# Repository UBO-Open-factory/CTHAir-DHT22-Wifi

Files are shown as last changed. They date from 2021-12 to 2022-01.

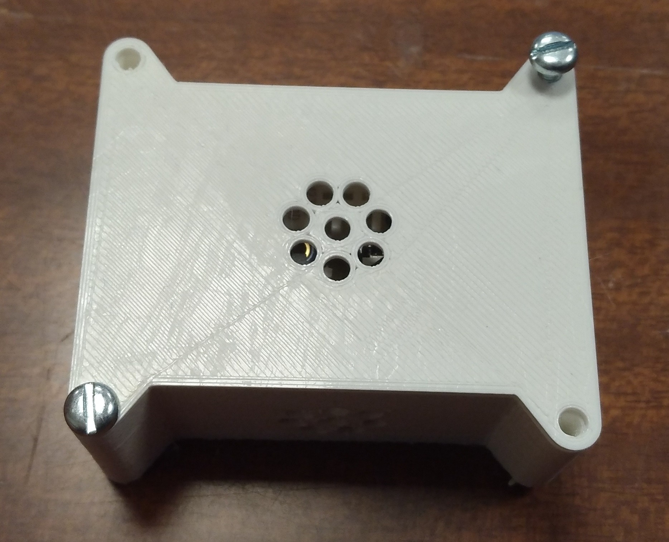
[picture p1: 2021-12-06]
Production/Photos/Boitier.jpg

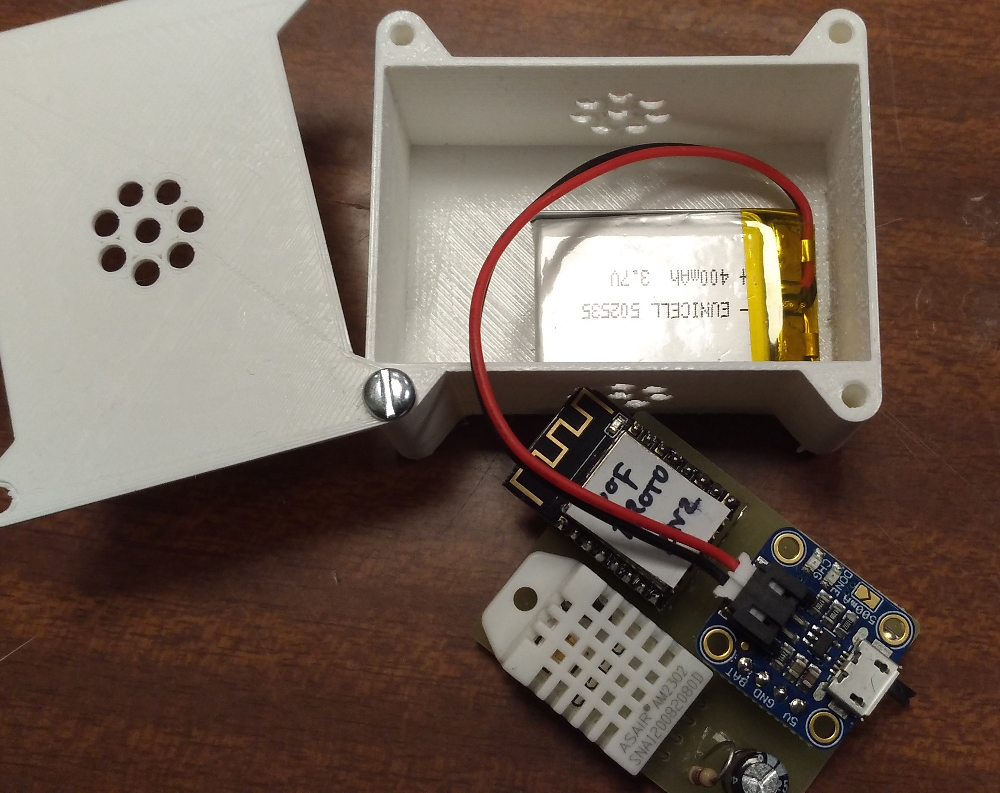
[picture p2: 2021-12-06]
Production/Photos/IMG_20211124_111949.jpg

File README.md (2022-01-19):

# CTHAir-DHT22-Wifi
Capteur de température et d'hygrométrie (DHT22) connecté à un réseau Wifi

Le capteur présenté ici permet de mesurer la température et l'hygrométrie d'un lieu puis d'envoyer ces informations par Wifi à un serveur de données.

<h1>Description</h1>
    Il intègre :
    <ul>
        <li>un capteur spécifique pouvant mesurer à la fois la température et l'hygrométrie de l'air</li>
        <li>un microcontrôleur gérant le fonctionnement de l'ensemble</li>
        <li>un chargeur de batterie  (https://www.robotshop.com/eu/fr/chargeur-batteries-lipo-micro-usb-adafruit.html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)</li>
        <li>un interrupteur On/Off</li>
        <li>Quelques composants discrets pour le fonctionnement du microcontôleur.</li>
    </ul>
    Il se présente sous la forme d'un petit boitier de 58 x 50 x 26 mm perc de quelques trous intégrant la carte électronique et une batterie.

<h1>Fonctionnement</h1>
    Le module réalise une mesure de température, une mesure d'hygrométrie et une mesure de la tension de la batterie.<br>
    Il se connecte ensuite à un réseau Wifi dont on lui a comuniqué les paramètres (SSID et mot de passe).<br>
    Puis il envoie les données sur un centre de données  dont on lui a communiqué l'adresse. Parmi les données envoyées figure un identifiant qui permettra au centre de données de savoir de quel module il reçoit des informations et donc comment les enregistrer.<br>
    Enfin il se met en veille pour une durée programmée après laquelle il recommencera un cycle de mesure/envoi/sommeil...

<h1>Electronique</h1>
    <h2>Version 2.4</h2>
    Elle est composée :
    <ul>
        <li>d'une carte électronique qui mesure 36 x 44 mm. Elle est composée d'un circuit simple face. Le schéma électrique et le schéma d'implantation sont données dans le répertoire "Electronique" au format Eagle et PDF.</li>
        <li>d'un ESP8266-12 Wifi (https://www.conrad.fr/p/joy-it-esp8266-module-uart-wifi-esp12-f-1-pcs-1707668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). Il est programmé pour réaliser toutes les fonctions du module. </li>
        <li>d'un chargeur pour batteries LiPo (https://www.adafruit.com/product/1904). Ce chrageur peut accepter toue batterie LiPo de 3.7V jusqu'à 5000 mAh. Il possède un prise batterie spécifique (JST2) ainsi qu'un prise de charge type USB mico.</li>
        <li>d'un capteur de température et hygrométrie relative (HR) DHT22 (https://www.robot-maker.com/shop/capteurs/31-dht22-31.html). Il peut mesurer des températures comprises entre 140 et +80°C avec une marge d'erreur de 0.5°C. Il peut mesurer un taux d'humidité de 0% à 100% avec une marge d'erreur de 2%.</li>
        <li>un régulateur "low drop" (placé côté pistes de la carte électronique) dont le rôle est de ramener la tension batterie à une tension de acceptable pour le fonctionnement du module (typiquement 3,3 V).</li>
        <li>Quelques composants dont les rôles sont multiples (filtrage d'alimentation, polarisation de certaines broches de l'ESP8266 pour le démarrage).</li>
    </ul>
    L'assemblage de la carte électronique est décrit dans le document "Assemblage" dans le répertoire "Documentation".
    <br>
    <h2>Version 3.1</h2>
    Elle est  composée des mêmes composants que l'électronique V2.4. La seule différence tient dans la carte électronique dont le schéma électrique est légèrement différent pour alimenter le DHT22 par un GPIO de l'ESP.
    Son montage est identique à la carte V2.4 à l'exception de l'emplacement des résistances. Les fichiers Eagle fournis donnent la nouvelle implantation.

<h1>Programme</h1>
    Le programme est décomposé en plusieurs fichiers disponibles dans le répertoire "programmation".
    L'ESP se programme (par exemple) avec l'IDE Arduino et à l'aide du programmateur décrit ci-dessous.
    <h2>Version 1.0</h2>
    Cette version utilise le protocole HTTP associé à un Fingerprint.
    <ul>
        <li>Le fichier "CTHAir_DHT22_Wifi_v1_0.ino" qui contient le programme principal.</li>
        <li>Le fichier "variables.h" qui contient les variables principales de fonctionnement du programme. Notamment l'identifiant du module qui sera transmis avec les données mesurées. Cet identifiant permettra qu centre de données de savoir quel module envoie des données.</li>
        <li>Le fichier "wifi_data.h" qui contient les paramètres de connection à un réseau Wifi. Les deux paramètres sont a adapter en fonction du réseau auquel on veut se connecter.</li>
        <li>Le fichier "server_data.h" qui contient les paramètres du serveur de données sur lequel on veut envoyer les données (hote, URL, port et fingerprint).</li>
        <li>Le fichier "type_converter.h" qui contient quelques fonctions utiles pour trnasformer des variables numériques en chaines de caractères formatées.</li>
    </ul>
    il est nécessaire de renseigner : 
        ssid et mod de passe dans le fichier "wifi_data.h"
        host, url et fingerprint dans le fichier "server_data.h"
        identifiant dans "variables.h"
    <br>
<h2>Version 1.1</h2>
    Dérivée de la version 1.0 elle n'utilise plus de fingerprint. LE reste fonctionne de la même manière.
    Il sera donc nécessaire de renseigner les mêmes données que dans la version 1.0 (sauf le fingerprint) avant de programmer l'ESP12.
    <h2>Version 2.0</h2>
    Similaire à la version 1.0 sur le plan de l'organisation. Seul la partie principale change pour s'adapter à l'alimentation du DHT22 par un GPIO.
    De ce fait il sera nécessaire de renseigner les mêmes données que dans la version 1.0 (sauf le fingerprint) avant de programmer l'ESP12.

<h1>Programmateur V1</h1>
    La programmation de l'ESP nécessite passe par une liaison UART et un convertisseur UART/USB pour communiquer avec un ordinateur de bureau. La solution adoptée a été de modifier un NodeMCU en enlevant l'ESP présent sur celui-ci et en le remplaçant par deux connecteurs. Ceci permet d'insérer des ESP à programmer.<br>
    Mise en garde : le désoudage de l'ESP et la soudure des connecteurs est un peu délicate. Une photo du programmateur est dsponible dans le répertoire "programmateur"

<h1>Batteries</h1>
    Les batteries utilisables sont de type LiPo 3.7V. Plusieurs capacités sont disponibles (250 mAh, 400 mAh, 1000 mAh et 5000 mAh).

<h1>Boitier V1</h1>
        Cette version n'accepte que les batteries jusqu'à 1000mAh inclus.
        LEs plans sont donnés dans le répertoire "Boitier V1"

<h1>Table de compatibilité</h1>
    Le tableau suivant indique les compatibilités entre le matériel et le logiciel.
<table>
    <tr>
        <td></td>
        <td><b>UOFPROTO2</b></td>
        <td><b>UOFPROTO3</b></td>
    </tr>
    <tr>
        <td><b>Electronique</b></td>
        <td>V 2.4</td>
        <td>V 3.1</td>
    </tr>
    <tr>
        <td><b>Programme</b></td>
        <td>V1.0<br>V1.1</td>
        <td>V2.0</td>
    </tr>
    <tr>
        <td><b>Boitier</b></td>
        <td>V1</td>
        <td>V1</td>
    </tr>
    <tr>
        <td><b>Programmateur</b></td>
        <td>V1</td>
        <td>V1</td>
    </tr>
</table>

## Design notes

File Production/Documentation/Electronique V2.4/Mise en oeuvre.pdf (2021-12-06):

## MISE EN OEUVRE DES CAPTEURS

Matériel nécessaire : un petit tournevis plat

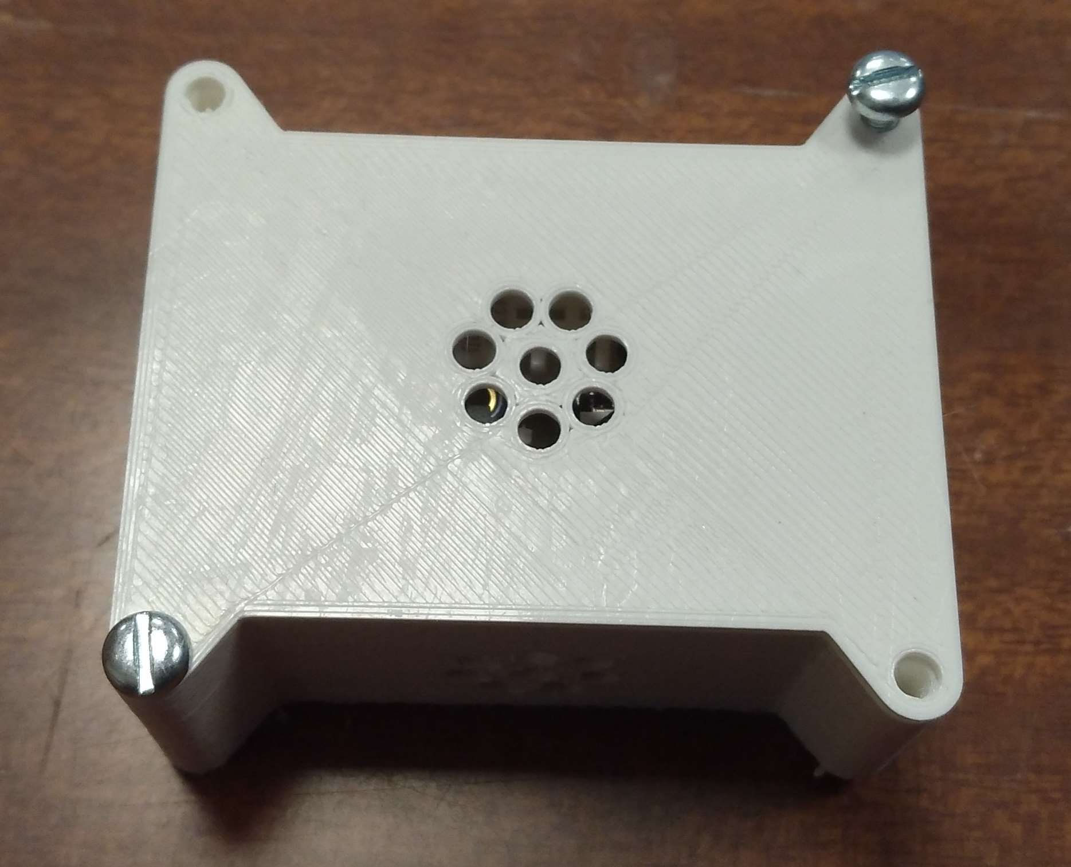
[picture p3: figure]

1 – Dévisser une des vis du couvercle

2 – Faire pivoter le couvercle autour de l’autre vis

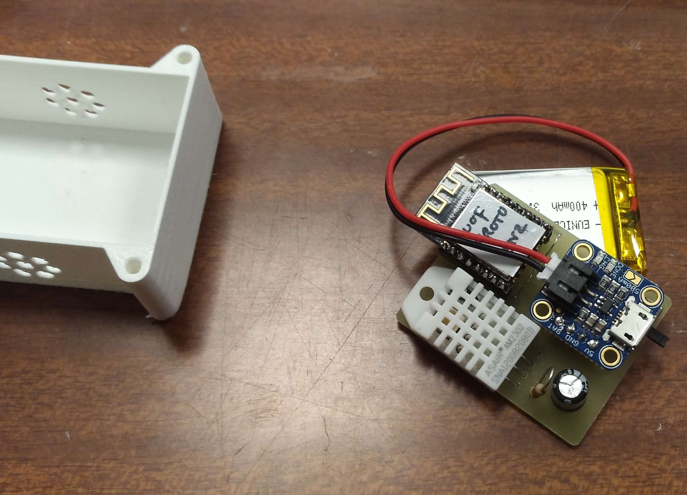
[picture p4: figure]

3 – Extraire la partie électronique du boitier

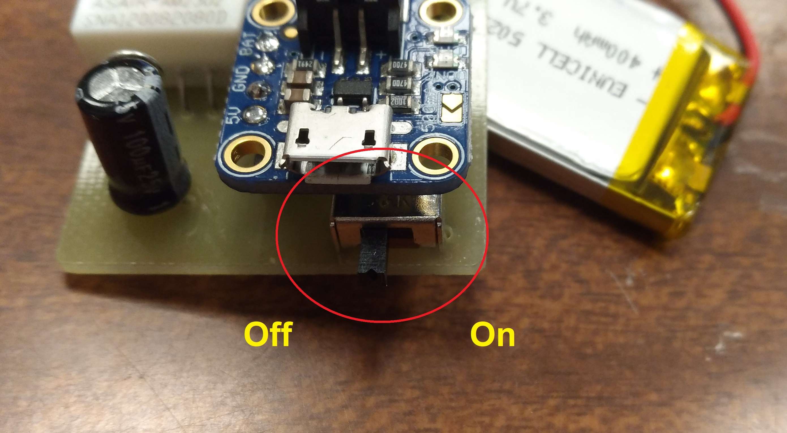
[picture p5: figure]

4 – Mettre l’interrupteur sur ON

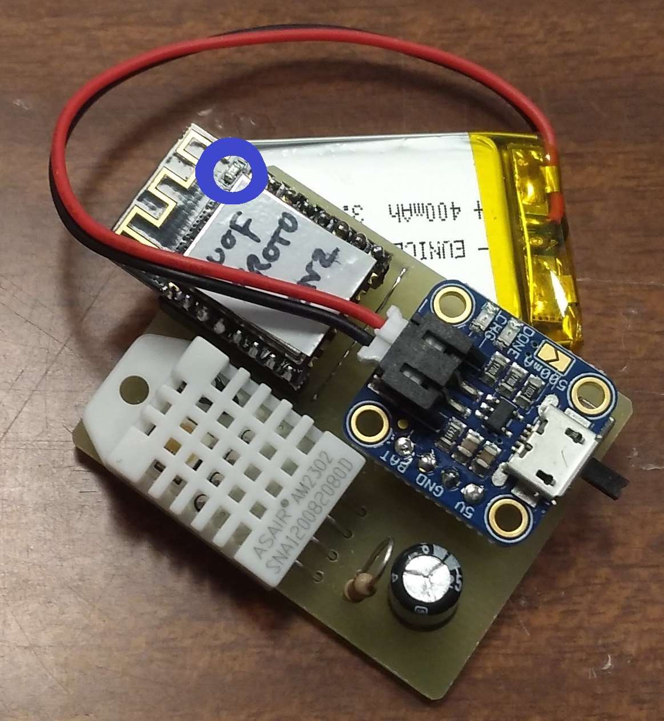
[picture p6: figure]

La led bleue doit émettre un flash bref lors de la mise sous tension

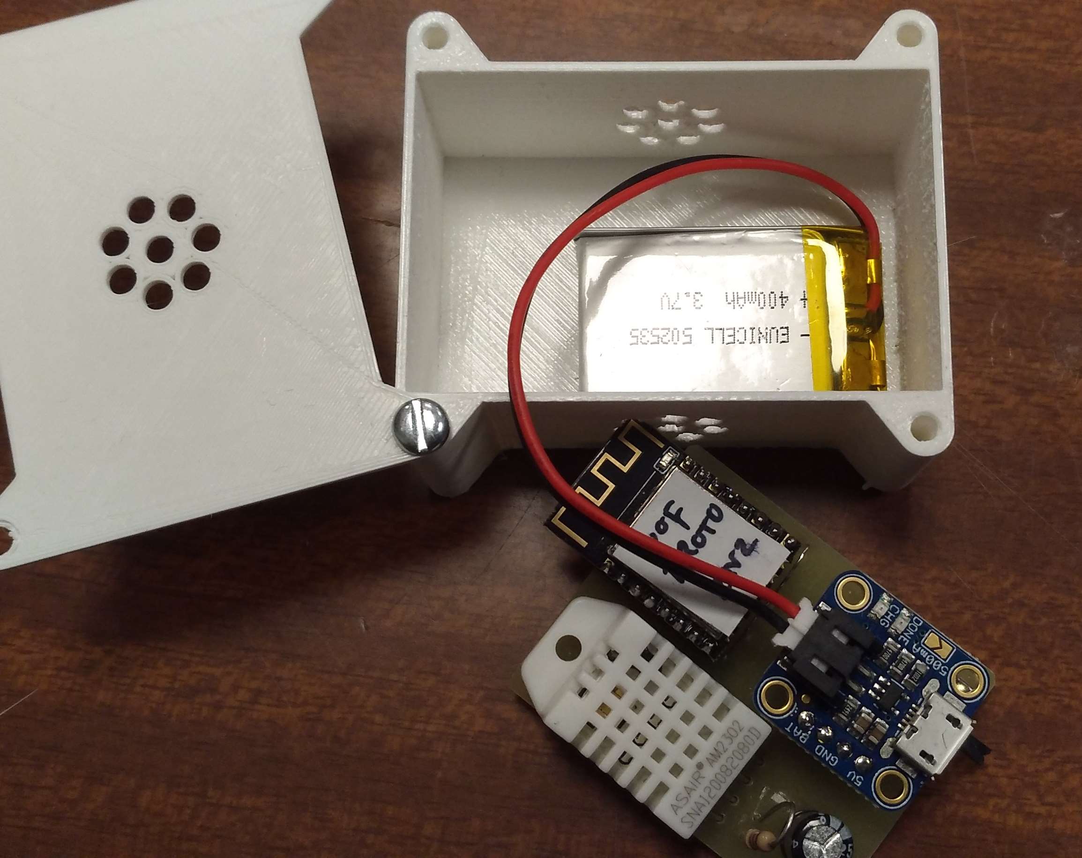
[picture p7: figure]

5 – Insérer la batterie (elle ne rentre pas dans l’autre sens)

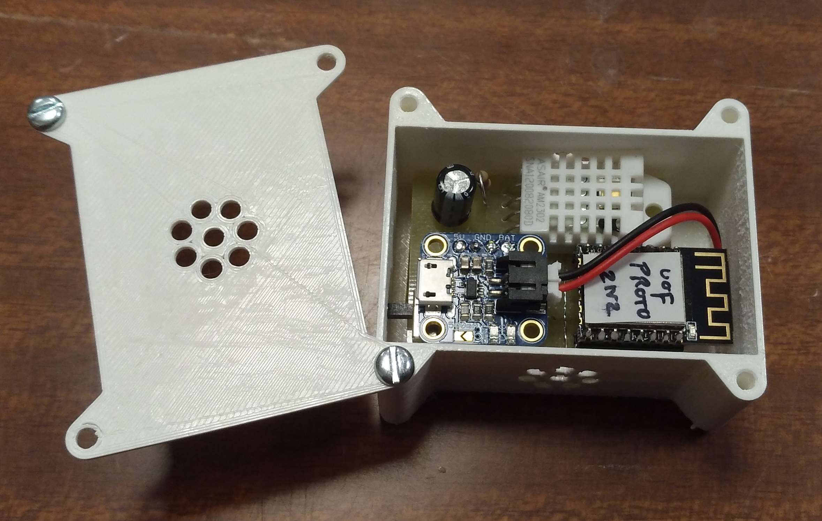
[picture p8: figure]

6 – Remettre la carte électronique en place

7 - refermer le couvercle

## Recharger la batterie :

Ouvrir le module comme ci-dessus,
Mettre le module sur Off
brancher un chargeur de téléphone (prise usb mini)=> la led rouge s’allume sur le chargeur
Lorsque la batterie est chargée, une led verte s’allume et la led rouge s’éteint. Remettre le module en fonctionnement .

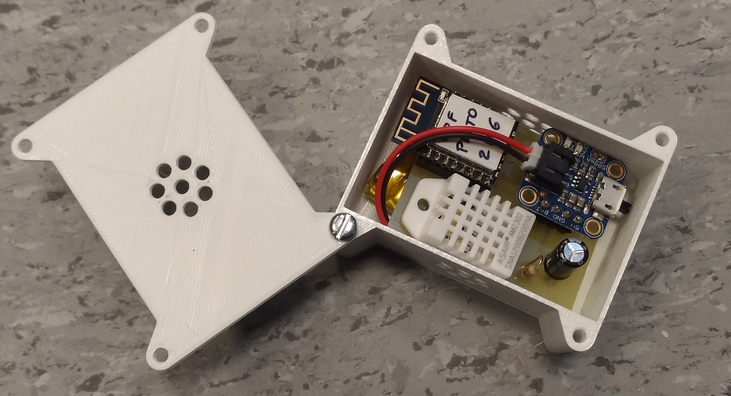
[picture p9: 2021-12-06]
Production/Photos/IMG_20211124_140635 cropé.jpg

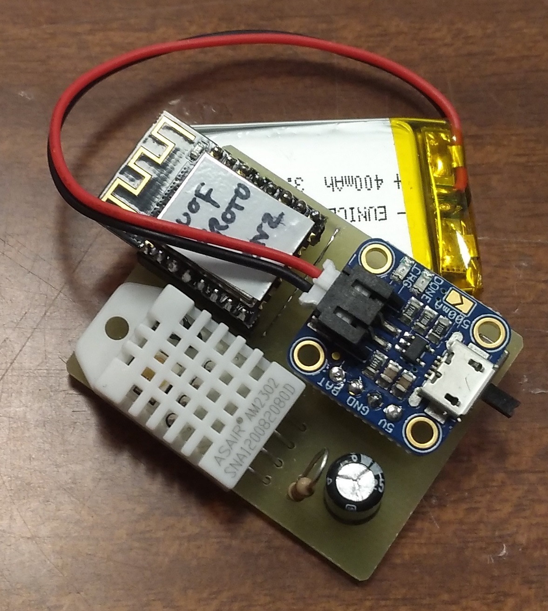
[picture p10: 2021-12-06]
Production/Photos/Module électronique.jpg

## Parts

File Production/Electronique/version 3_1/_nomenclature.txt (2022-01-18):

Montage :

Nomenclature

		ESP12									1
		Connecteur femelle 2mm (1 x 8 br) 		2
		connecteur mâle 2mm (1 x 8 br)			2
		capteur DHT22							1
		régulateur low drop 3v3					1
		chargeur Adafruit microlipo				1
		résistance 1/4W 330 kilo ohms			1
		résistance 1/4W 100 kilo ohms			1
		résistance 1/4W  12 kilo ohms			2
		Condensateur chimique verical 100 µF	1

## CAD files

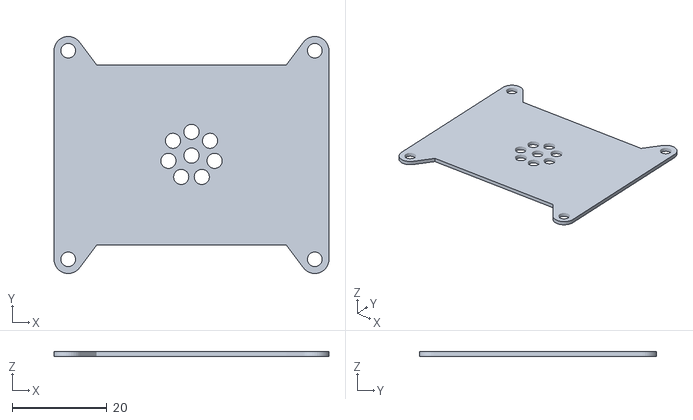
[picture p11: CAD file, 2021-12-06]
Production/Boitier/V1/couvercle.stl
58.0 x 50.0 x 1.00

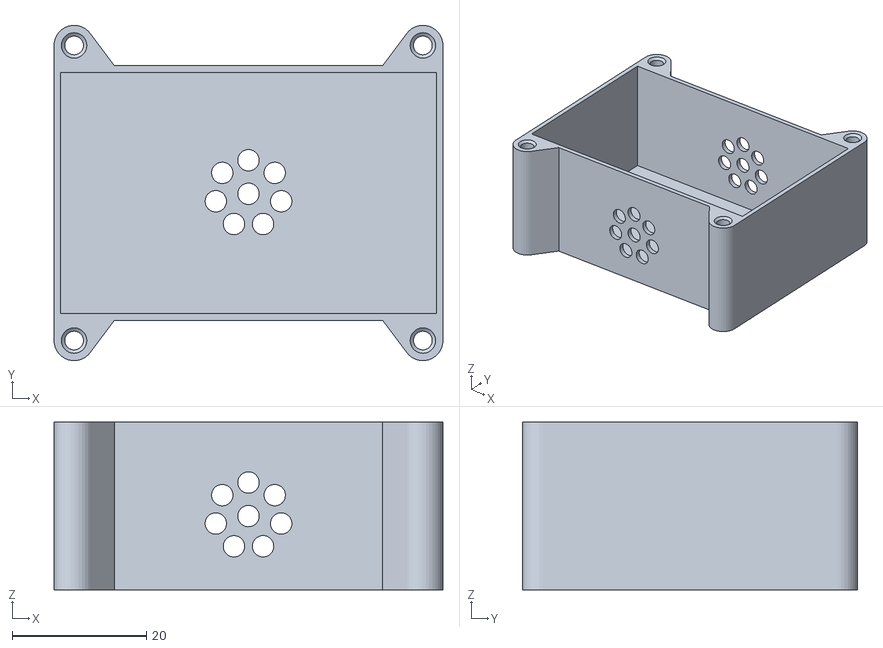
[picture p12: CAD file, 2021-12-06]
Production/Boitier/V1/boitier.stl
58.0 x 50.0 x 25.0

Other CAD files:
Production/Boitier/V1/Boitier.dxf
Production/Boitier/V1/Boitier.f3d

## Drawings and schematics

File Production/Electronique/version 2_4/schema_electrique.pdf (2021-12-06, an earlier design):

A

A

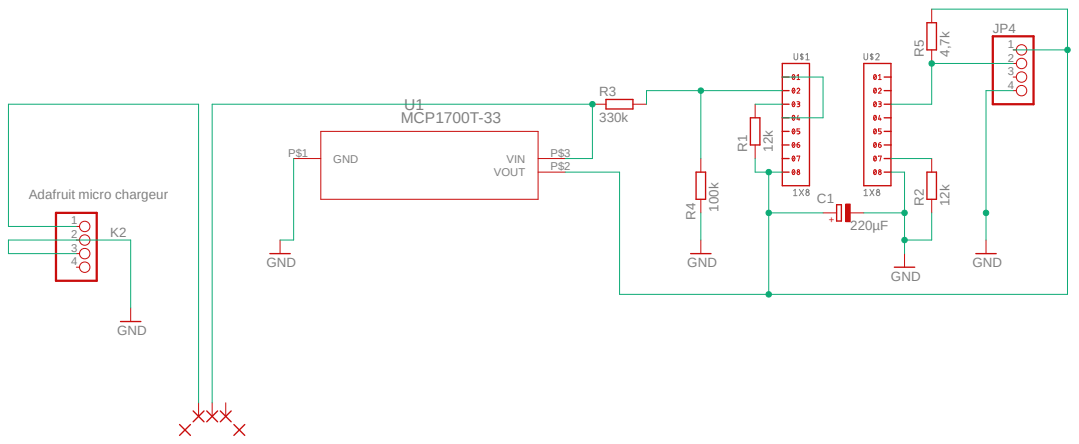
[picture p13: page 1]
GND; MCP1700T-33; GND ¹²k; GND P$1; VOUT; P$2 VIN; Sheet:; module_A

Adafruit micro chargeur

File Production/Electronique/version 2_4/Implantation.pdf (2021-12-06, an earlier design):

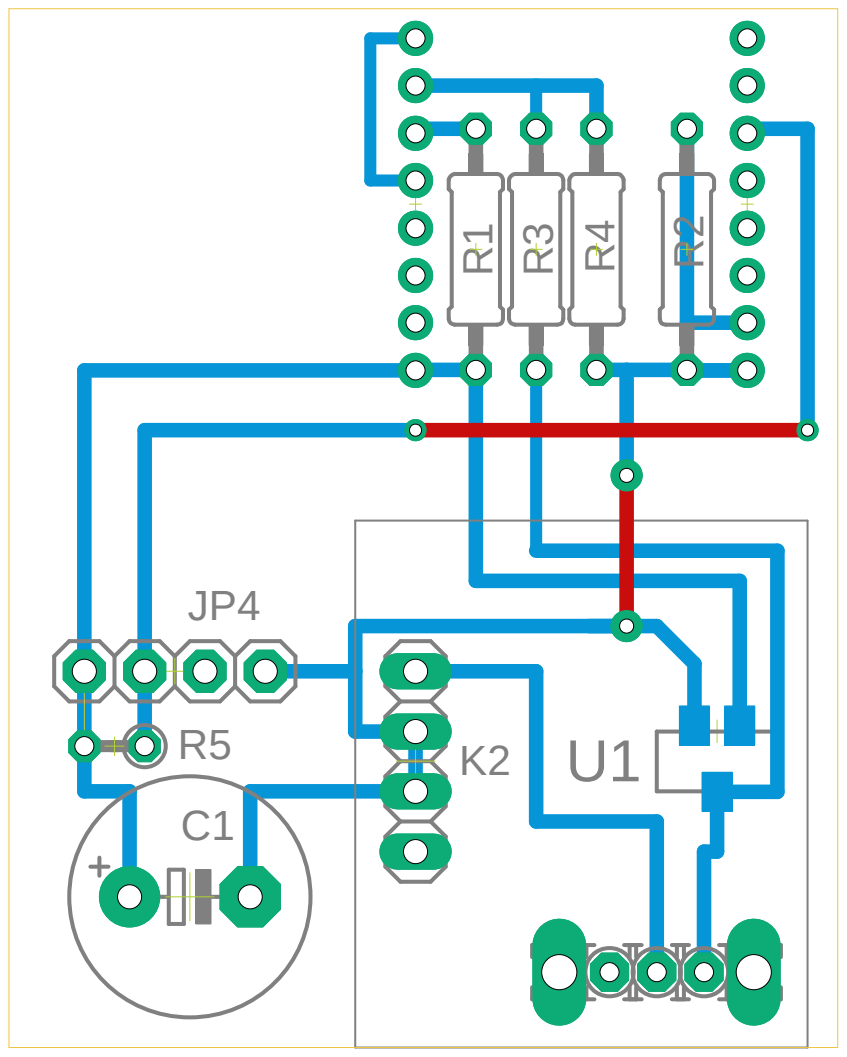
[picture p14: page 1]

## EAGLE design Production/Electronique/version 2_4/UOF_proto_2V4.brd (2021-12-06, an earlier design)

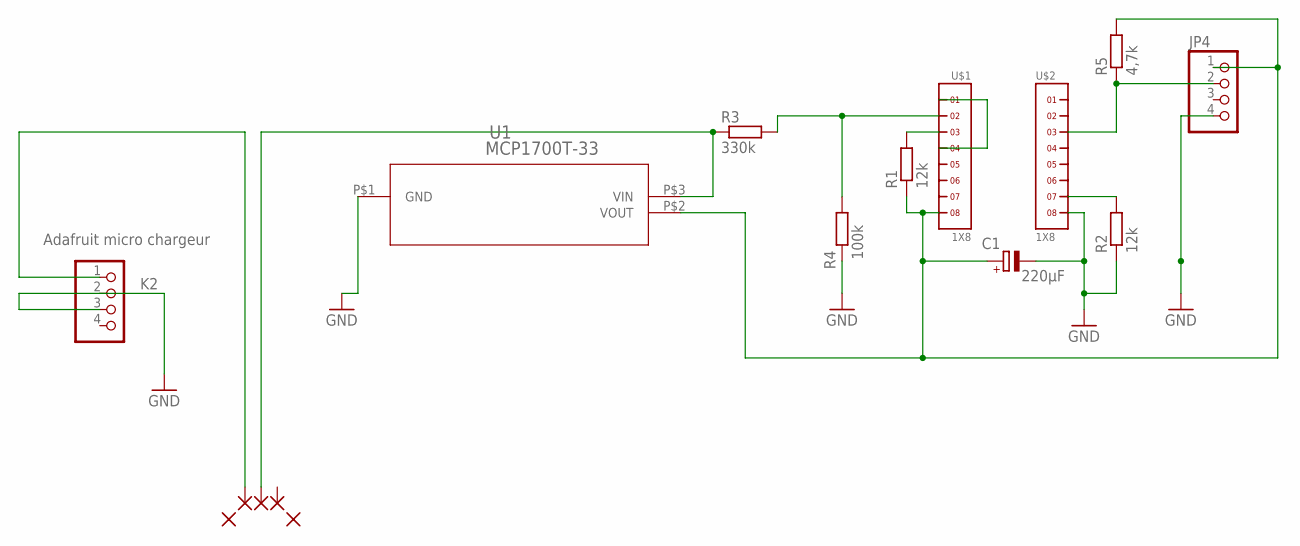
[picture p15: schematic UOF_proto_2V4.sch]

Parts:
C1: 220µF; E5-10,5
JP4: PINHD-1X4; 1X04
K2: Adafruit micro chargeur; 1X04
PAD1, PAD2, PAD3: 1,6/0,8
PAD4, PAD5: N_2,0/1,5; 2,0/1,5
R1, R2: 12k; 0207/10
R3: 330k; 0207/10
R4: 100k; 0207/10
R5: 4,7k; 0204V
U1: MCP1700T-33; SOT-23
U$1, U$2: 1X8

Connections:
GND: C1.-, JP4.4, K2.2, K2.3, R2.1, R4.2, U1.P$1 (GND), U$2.8
unnamed: R3.2, R4.1, U$1.2
unnamed: K2.1, PAD1.1
unnamed: R2.2, U$2.7
unnamed: C1.+, JP4.1, R1.1, R5.2, U1.P$2 (VOUT), U$1.8
unnamed: U$1.1, U$1.4
unnamed: PAD2.1, R3.1, U1.P$3 (VIN)
unnamed: R1.2, U$1.3
unnamed: JP4.2, R5.1, U$2.3

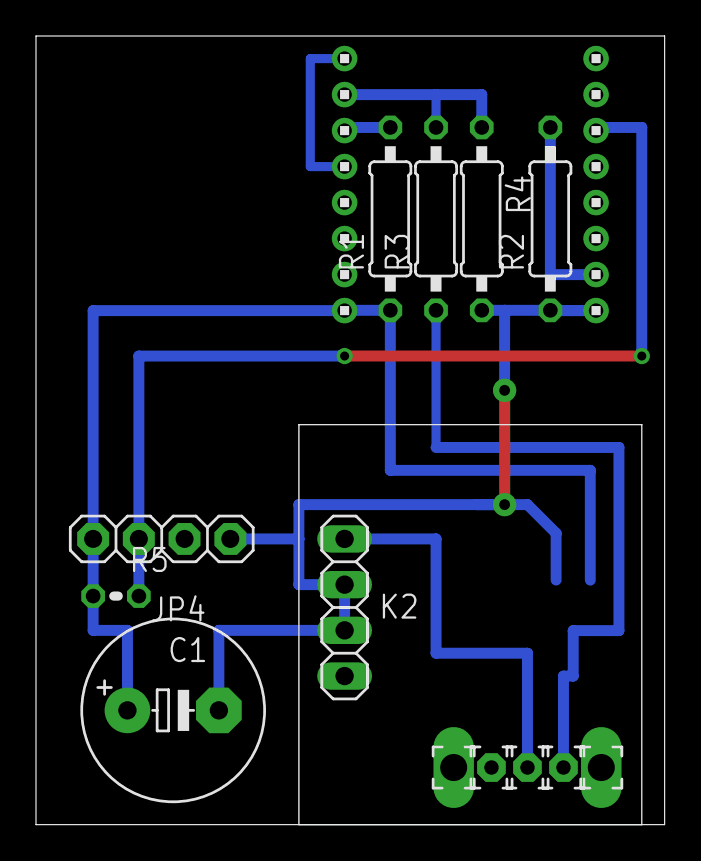
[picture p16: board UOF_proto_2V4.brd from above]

Board: 2 copper layers, 34.9 x 43.8 mm, 16 parts (1 on the bottom side), 9 nets.

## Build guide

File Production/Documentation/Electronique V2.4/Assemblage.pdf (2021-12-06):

# CTHAir-DHT22-Wifi

## Manuel d’assemblage

### Liste des composants

- 1 PCB (voir ci-dessus)
- 1 capteur DHT22
- 1 ESP12 E ou F
- 2 connecteurs femelles 1 x 8 contact au pas de 2 mm
- 2 connecteurs mâles 1 x 8 contact au pas de 2 mm
- 1 connecteur mâle 1 x 4 contacts au pas de 2,54 mm
- 1 microchargeur Adafruit ref. 1904
- 1 interrupteur miniature ref. OS102011MA1QN1
- 1 condensateur chimique 100µF 100V (C1)
- 1 résistance 4,7 k ¼ W (R5)
- 2 résistances de 12 k ¼ W (R1 et R2)
- 1 résistance de 330 k ¼ W (R3)
- 1 résistance de 100 k ¼ W(R4)
- 1 batterie Lithium ion 3,7v. L’intensité délivrable définira l’autonomie du module.
- 1 régulateur low-drop CMS MCP1700T-3302E/TT

### Assemblage

Avant toute soudure, s’assurer de la continuité des différentes pistes et de l’isolation entre les différentes pistes.

Souder le régulateur au dos de la carte

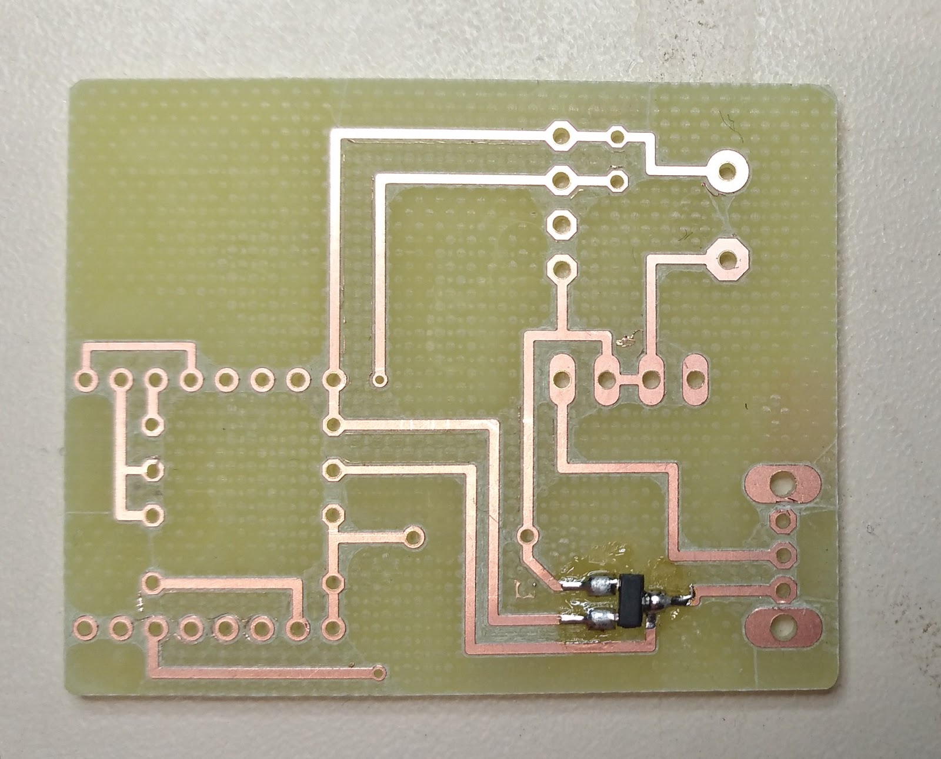
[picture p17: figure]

Souder les deux straps

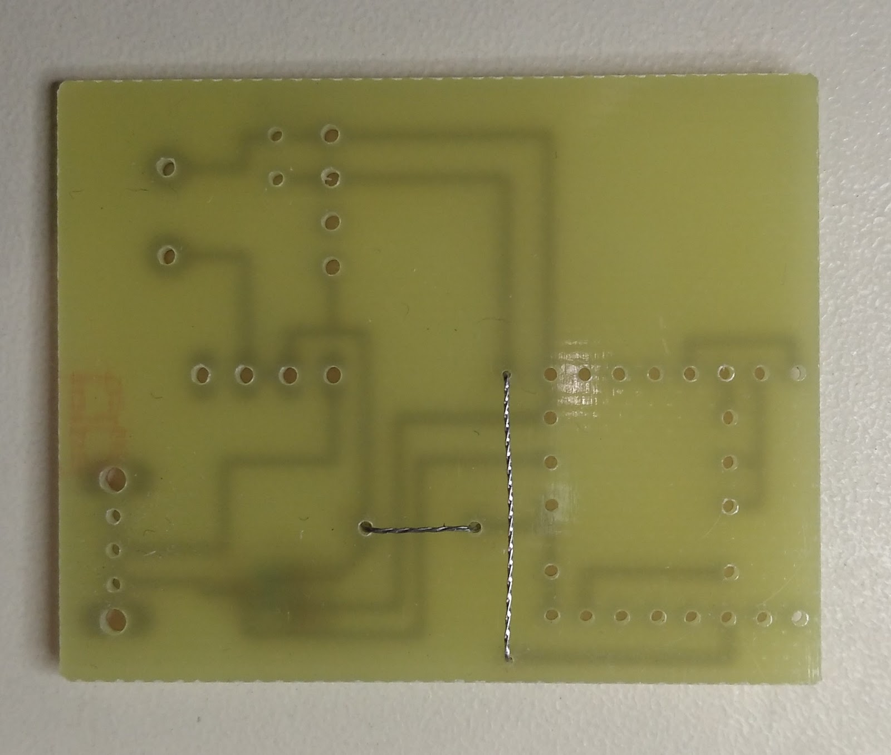
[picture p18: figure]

Souder l’interrupteur

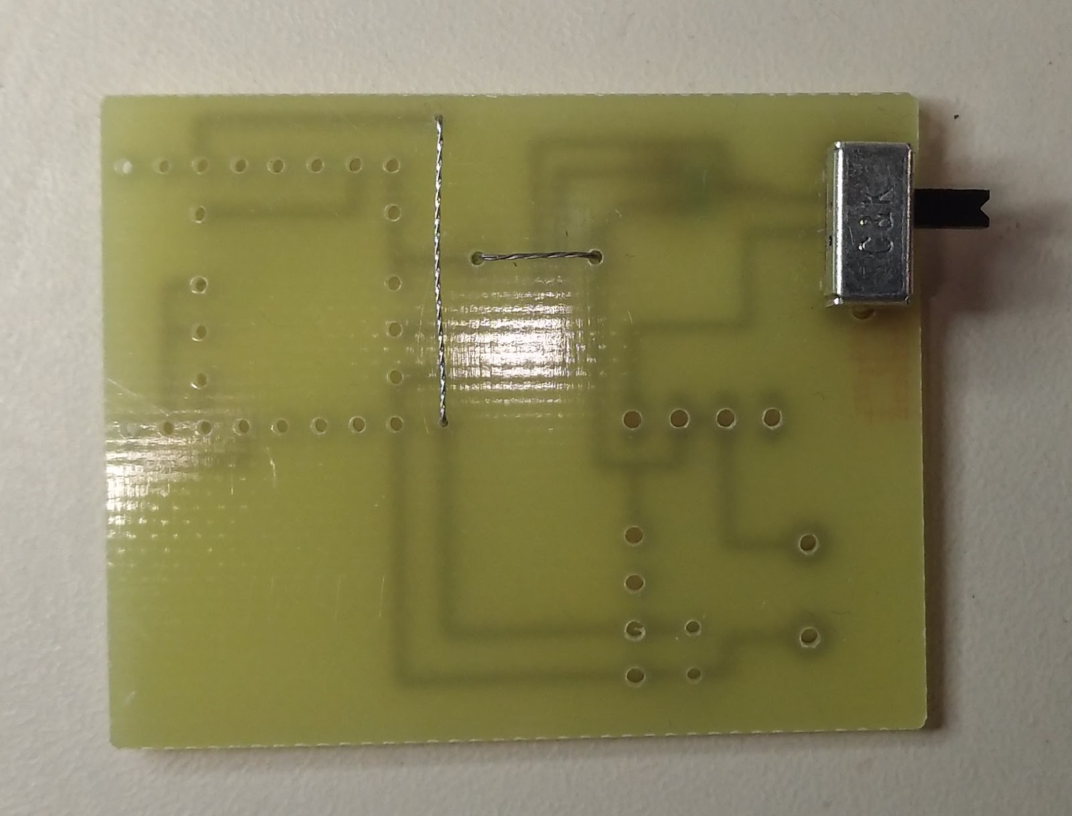
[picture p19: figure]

Souder les résistances R1 à R4

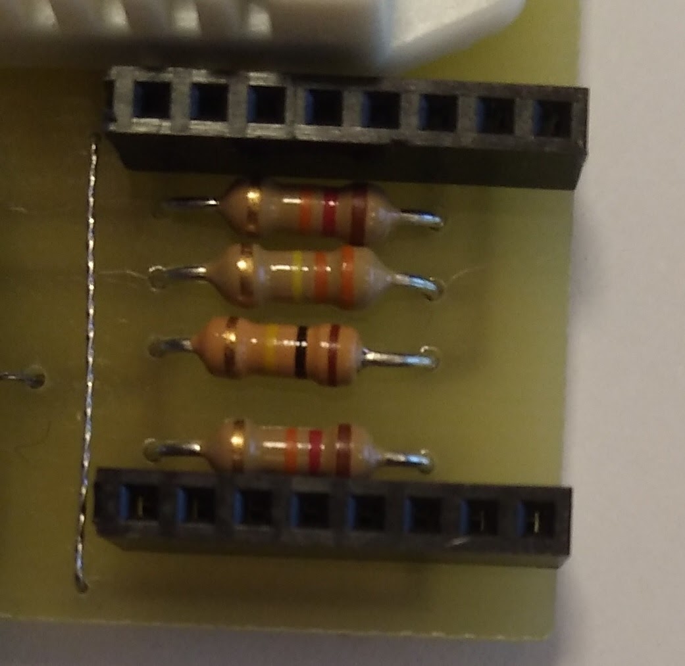
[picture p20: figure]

Enficher les connecteurs mâle 1x8 dans les connecteurs femelles 1 x 8. placer les connecteurs femelle sur le PCB et l’ESP sur les connecteurs mâles. Souder l’ESP sur les connecteurs mâle puis souder les connecteurs femelle sur la carte, après l’avoir retournée.

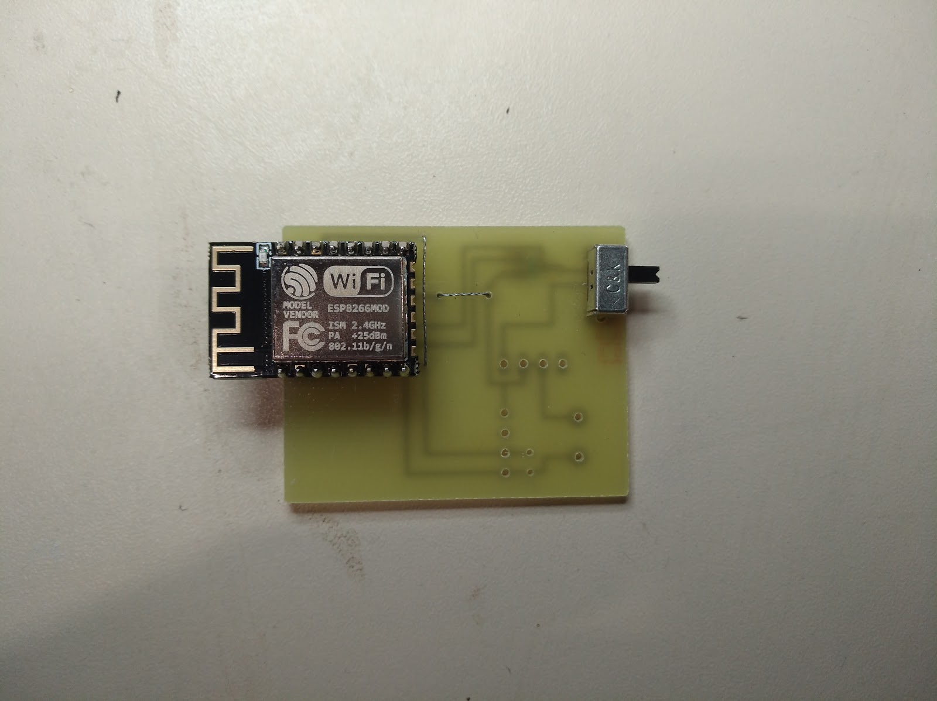
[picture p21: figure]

Souder le connecteur mâle 1x4 puis souder le microchargeur sur le connecteur mâle 1 x 4 en positionnant la prise usb au dessus de l’interrupteur. Prendre soin de souder le microchargeur au plus haut sur le connecteur de manière à ce que la prise batterie ne soit pas gênée par l’ESP 12.

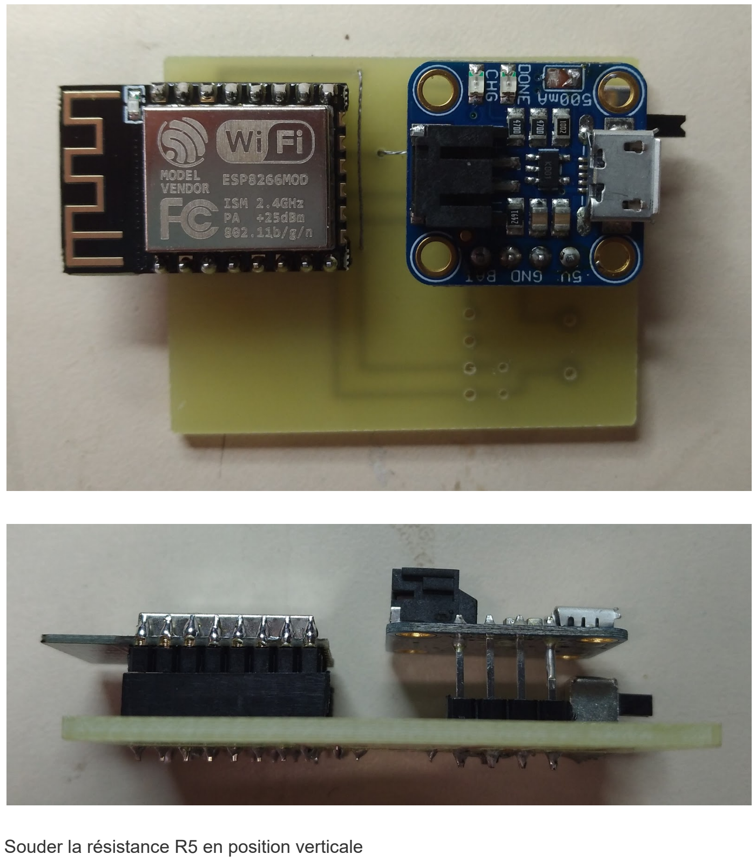
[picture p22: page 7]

Souder la résistance R5 en position verticale

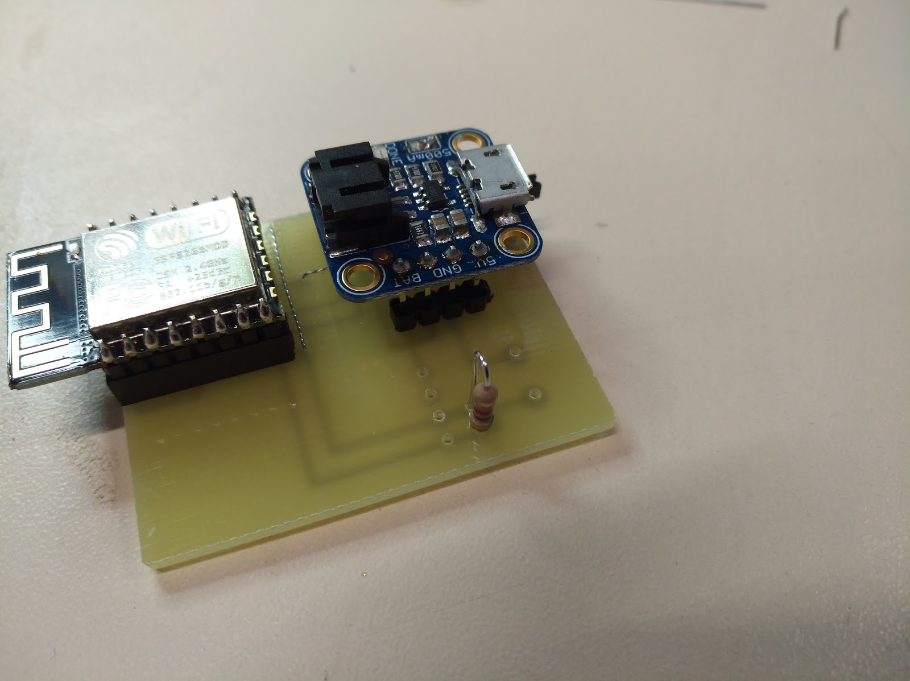
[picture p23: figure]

Souder le condensateur (attention à la polarité).

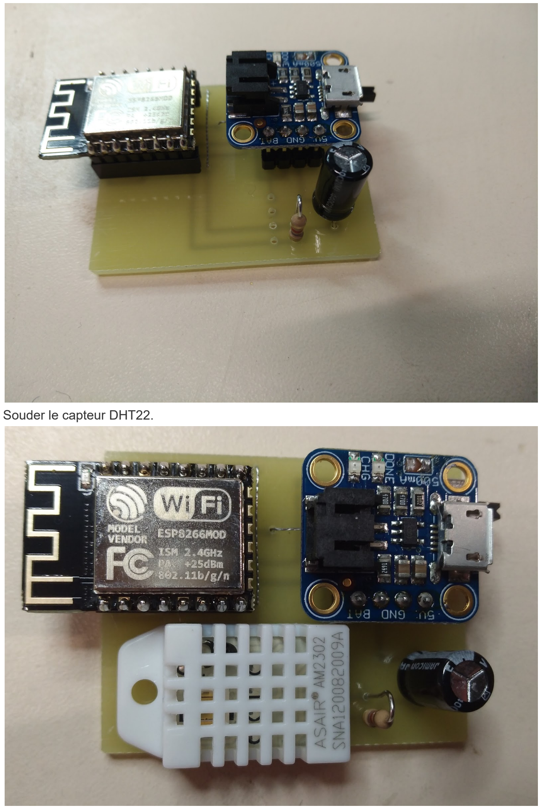
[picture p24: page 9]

Souder le capteur DHT22.

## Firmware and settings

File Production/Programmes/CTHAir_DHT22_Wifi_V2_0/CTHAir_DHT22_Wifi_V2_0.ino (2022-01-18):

/*
 *          PROTOTYPE DE CAPTEUR DE TEMPERATURE ET D'HUMIDITE POUR PASSERELLE
 *          
 *  - Description  :  ce programme est intégré dans le module UOF PROTO2V2 composé 
 *                    d'un ESP8266 associé à un capteur DHT22.  L'ESP est entouré de 
 *                    quelques résistances pour lui permettre de démarrer.
 *                    Il est alimenté par une batterie reliée à un chargeur intégré
 *          
 *                    Nécessite l'installation du Core ESP8266 pour arduino disponible ici : https://github.com/esp8266/Arduino
 *                    Nécessite l'installation de la bibliothéque DHT disponible ici : http://librarymanager/All#DHTesp
 *                    
 *  - Auteur       : Laurent Marchal(UBO OpenFactory)
* 
* - Date           : oct 2021
* 
* - Licence        : CC-BY-SA
* 
* 
* 
* 
* - Versions       : 
* 
*                     0.1
*                         - Répartition des données sensibles dans différents fichiers locaux
*                         - initialisation du module
*                         - alimentation du module
*                         - initialisation du capteur et mesures des paramètres
*                         - connection au réseau Wifi (timeout)
*                         - création d'un client pour le serveur TOCIO
*                         - envoi des mesures vers TOCIO (pas de fingerprint)
*                         - coupure du capteur
*                         - mise en sommeil 
*/



// inclusion des bibliothèques
#include "DHTesp.h"
#include <ESP8266WiFi.h>
#include <WiFiClientSecure.h>

// fichiers locaux
#include "variables.h";
#include "wifi_data.h";
#include "server_data.h";
#include "type_converter.h";
#include "Tocio.h";

// instanciation du capteur
DHTesp dht;

// constantes
 #define DHTPIN 4       // DHT relié à la broche GPIO5
 #define DHTPOWERPIN  5

// variables
float temperature = 0-98.5;
float hygrometrie = 12;
int batterie = 0;
String adresse_mac = "";
String chaine_a_envoyer = "";

void setup() {
  // initialisation de la liaison série
  Serial.begin(115200);
  while (!Serial){
    delay(20);
  }

  #if (DEBUG)
  Serial.println(" Liaison USB prête !");
  #endif

  pinMode(DHTPOWERPIN,OUTPUT);
  digitalWrite(DHTPOWERPIN,HIGH);
  
  // initialisation du capteur sur la broche correspondante
  dht.setup(DHTPIN, DHTesp::DHT22); // Connect DHT sensor to GPIO 5

  // connection au reseau Wifi
  if (connection_WiFi()) {

    // determination de l'identifiant
    if (identifiant == "") identifiant = adresse_mac;
    
    // fin de l'initialisation
    #if (DEBUG)
    Serial.println("Initialisation terminée.");
    Serial.println("");
    Serial.print ("Identifiant du module : " + identifiant);
    Serial.println("");
    #endif
    // mesure du taux d'humidité
    hygrometrie = dht.getHumidity();
    #if (DEBUG)
    Serial.println (hygrometrie);
    #endif
    // calibration si la lecture  échouée
    if (isnan(hygrometrie)) hygrometrie = 999;
    Serial.println (hygrometrie);
    
    // mesure de la température
    temperature = dht.getTemperature();
    #if (DEBUG)
    Serial.println (temperature);
    #endif
    
    // calibration si la lecture  échouée
    if (isnan(temperature)) temperature = -99.99;
    Serial.println (temperature);

    // extinction du capteur
      digitalWrite(DHTPOWERPIN,LOW);
    
    // mesure de la tension batterie (en pas de CAN)
    batterie = analogRead(A0);
    
    // formatage des mesures dans une chaine de caractères
    #if (DEBUG)
    Serial.print ("hygrometrie : ");
    #endif
    chaine_a_envoyer = float_to_string(hygrometrie,false, 3,0);
    #if (DEBUG)
    Serial.print ("température : ");
    #endif
    chaine_a_envoyer += float_to_string(temperature,true, 2, 2);
    chaine_a_envoyer += unsignedint_to_string(batterie, 4);
    
    #if (DEBUG)
    Serial.println ("Chaine à envoyer : <" + chaine_a_envoyer + ">");
    #endif
   
  
    // envoie les mesures
    String res = sendDataInHTTPSRequest(chaine_a_envoyer);
    #if (DEBUG)
    Serial.println ("C/R : " + res);
    #endif
    

  }
  // mise en sommeil
  #if (DEBUG)
  Serial.print ("Mise en sommeil pour ");
  Serial.print (String (duree_mise_en_sommeil));
  Serial.println (" minutes");
  #endif
  ESP.deepSleep(duree_mise_en_sommeil*60000000);
}

void loop() {
  // rien ici
}


// **********************************************************
//*****          F O N C T I O N S
// **********************************************************



bool connection_WiFi() {
  unsigned long debut = millis();
  #if (DEBUG)
  Serial.print("connecting to ");
  Serial.println(ssid);
  #endif
  WiFi.mode(WIFI_STA);
  WiFi.begin(ssid, password);

  #if (DEBUG)
  Serial.println ("+----------------+");
  Serial.print("Adresse MAC : ");
  #endif
  adresse_mac = WiFi.macAddress();
  #if (DEBUG)
  Serial.println(adresse_mac);
  Serial.println ("+----------------+");
  #endif
    
  while (WiFi.status() != WL_CONNECTED) {
    if ((millis() - debut) > (timeout_connection_wifi*1000)) {
      #if (DEBUG)
      Serial.println("");
      Serial.println ("Connection WIFI impossible");
      #endif
      return false;
    }
    delay(500);
    #if (DEBUG)
    Serial.print(".");
    #endif
  }
  #if (DEBUG)
  Serial.println("");
  Serial.println("WiFi connected");
  Serial.print("Adresse IP : ");
  Serial.println(IpAddress2String(WiFi.localIP()));
  #endif
  return true;
}

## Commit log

2021-12-06 Création
    [Boitier.dxf, Boitier.f3d, UOF_proto_2V4.brd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]
2022-01-18 implémentation de versions
    Ajout des version 1.1 et 2 pour le logiciel, 3.1 pour l'électronique
    [Boitier.dxf, Boitier.f3d, UOF_proto_2V4.brd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]
2022-01-18 correction de mise en page du read me
